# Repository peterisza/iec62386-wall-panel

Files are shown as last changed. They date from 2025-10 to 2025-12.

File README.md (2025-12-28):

This is a smart-home wall panel that is intended to be DALI-compatible when it's finished. It has sensors for temperature, humidity, air pressure, and CO2. Its front is customizable and user-swappable with up to 16 capacitive touch channels.

## Status / Important Notice

This project is a **prototype** and **not a consumer product**. It is under active development and may be incomplete, unstable, or non-compliant with relevant standards.

### DO NOT CONNECT TO A REAL DALI NETWORK (YET)

**Do not connect this device to any production / real DALI installation.**  
The current firmware is not DALI-compliant and is intended for development only. In its current state it will:
- transmit debug frames (e.g., 16-bit debug frames),
- respond incorrectly to forward frames (e.g., fixed/placeholder back frame behavior),
- cause unexpected bus behavior.

## Safety / Disclaimer

- Provided **AS IS**, **WITHOUT WARRANTY** of any kind (express or implied).
- You are solely responsible for verifying **electrical safety**, **EMC**, and **regulatory compliance** before any real-world installation or use.
- Not intended for **safety-critical** or life-safety applications (medical, fire protection, emergency systems, etc.).
- If you 3D-print the enclosure, use appropriate **flame-retardant** materials and follow local building and electrical codes.
- By using, building, or distributing this project (or derivatives), you accept that you do so **at your own risk**.

## DALI Compatibility, Certification, and Trademarks

This project is designed with future DALI compatibility in mind, but it is **NOT DALI certified**.

- Certification is performed by the **DALI Alliance / DiiA**. This project is **not certified** and **not affiliated** with the DALI Alliance / DiiA.
- “DALI” and related marks are trademarks of their respective owners. Any mention is for compatibility and informational purposes only.

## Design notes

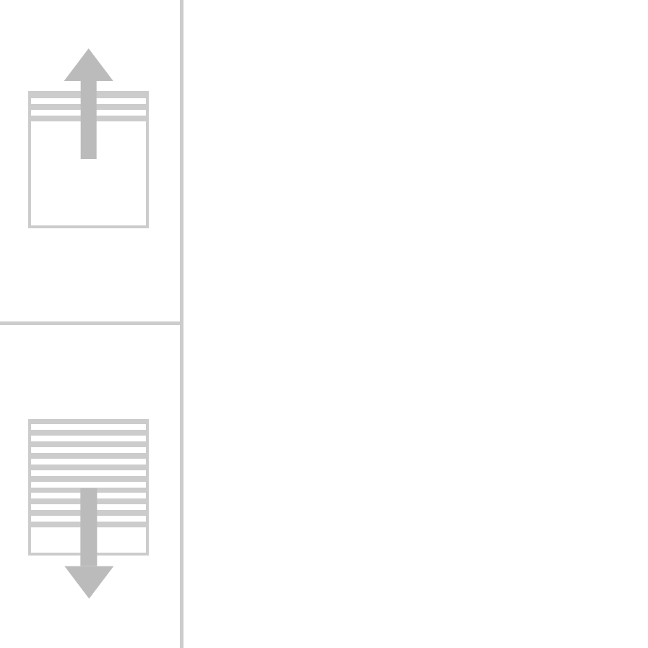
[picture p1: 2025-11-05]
enclosure/button1.png

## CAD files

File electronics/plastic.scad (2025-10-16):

size = 80.5;            
plate_thickness = 2.4;       
air_duct_th = 1.2;
air_duct_w = 8;
screw_enforcement_thickness = 1;
screw_head_height = 2;
pcb_th = 1.6;
box_size = 46;
box_max_r = 57.6/2;
conn_d = 10.5;
behind_pcb = 5;
screw_insulation_h = 3.5;
box_th = 1;
box_corner_r = 6;
clip_width = 10;
clip_h = 2;
screw_distance = 17.5;
screw_hole_d = 3.0;
panel_screw_insulation_d = 5.5;
box_screw_platform_hole_d = 6;
box_screw_hole_d = 3.6;
box_screw_tightness = 0.2;
box_panel_spacing = 0.2;
centered = true;
center = true;
box_start_z = plate_thickness/2;
box_height = conn_d + pcb_th + behind_pcb + box_th;
frame_th = 0;
frame_h = 0;

$fn=100;


module ring(d1, d2, h)
{
    difference() {
        cylinder(d = d1, h = h, center=true);
        cylinder(d = d2, h = h+1, center=true);
    }
}

module screw_head_holes(w, l, h) {
    distance = 30;        // a furatok közepe a középponttól (mm)
    hole_d = 15;
    
    for (ang = [0:90:270]) {
        rotate([0,0,ang])
        translate([distance, 0, 0])
        linear_extrude(h, scale=2.3, center=true)
        projection(cut = true)
        translate([-distance, 0, 0])
        intersection() {
                translate([distance, 0, 0])
                cylinder(d = l, h = h, center=true);

                ring(distance*2+w, distance*2-w, h);
        }
    };
}

module screw_holes(w, l, h) {
    distance = 30;        // a furatok közepe a középponttól (mm)
    hole_d = 15;
    
    intersection() {
        for (ang = [0:90:270]) {
            rotate([0,0,ang])
            translate([distance, 0, 0])
            cylinder(d = l, h = h, center=true);
        };
        ring(distance*2+w, distance*2-w, h);
    }
}



module connector_holes()
{
    distance = 38.6;
    margin = 0.25;
    translate([-distance/2, 0, 0])
       cube([2.65+margin, 25.6+margin, 20], center = true);
    translate([distance/2, 0, 0])
       cube([2.65+margin, 25.6+margin, 20], center = true);
    translate([0, -distance/2, 0])
        cube([14+margin, 2.65+margin, 20], center = true);
    translate([0, distance/2, 0])
        cube([14+margin, 2.65+margin, 20], center = true);
}

module main_plate()
{
    difference() {
        translate([0, 0, +frame_h/2])
        cube([size+2*frame_th, size+2*frame_th, plate_thickness+frame_h], center = centered);
        translate([0, 0, plate_thickness/2+frame_h/2+0.001])
        cube([size, size, frame_h], center = centered);
    }
}

module air_ducts()
{
    w = air_duct_w;
    t = air_duct_th+frame_h;
    pitch = 18;
    displacement = plate_thickness/2-t/2+0.001+frame_h;
    
    translate([-pitch, 0, displacement])
        cube([w, size+5, t], center = true);
    translate([pitch, 0, displacement])
        cube([w, size+5, t], center = true);
    translate([0, pitch, displacement])
        cube([size+5, w, t], center = true);
    translate([0, -pitch, displacement])
        cube([size+5, w, t], center = true);
}

module screw_platform(height, outer, inner)
{
    distance = screw_distance;
    for (ang = [0:90:270]) {
        rotate([0,0,ang])
            translate([-distance,-distance,-height/2])
                ring(outer, inner, height);
    }
}

module pcb_platform(height, outer, inner)
{
    distance = screw_distance;
    for (ang = [0:90:270]) {
        rotate([0,0,ang])
            translate([-distance,-distance,-height/2])
                difference() {
                    cube([outer, outer, height], center = true);
                    cylinder(d = inner, h = height+1, center=true);
                }
    }
}

module rounded_square(r, w, h)
{
    offset(r=r)
        offset(delta=-r)
            square([w, h], center=true);
}

module fucked_up_square(r, w, h)
{
        intersection()
        {
            square([w, h], center=true);
            circle(r = r);
        }
}

module box_guard()
{
    size = 2;
    h = clip_h + 1.5;
    spacing = 0.3;
    guard_h = 2;
    translate([0, 0, -box_start_z-guard_h])
        linear_extrude(guard_h)
        intersection() {
            difference() {
                fucked_up_square(box_max_r + spacing + 2.4, box_size+spacing*2+2.4, box_size+spacing*2+2.4);
                fucked_up_square(box_max_r + spacing, box_size+spacing*2, box_size+spacing*2);
            }
            /*fucked_up_square(box_max_r, box_size, box_size);*/
            circle(box_max_r);
        }
}

module box()
{
    w = box_size;
    h = box_size;
    r = box_corner_r;
    
    conn_w = 16;
    conn_h = 8+box_th;
    conn_x = -5;
    conn_d = behind_pcb + box_th - 0.5;
    
    box_screw_platform_h = behind_pcb - screw_insulation_h - 0.3;
    box_screw_platform_h2 = behind_pcb + box_screw_tightness;
    
    translate([0, 0, -box_height])
    difference() {
        union() {
            linear_extrude(box_height-0.1)
            difference() {
                fucked_up_square(box_max_r, w, h);
                fucked_up_square(box_max_r-box_th, w-box_th*2, h-box_th*2);
            }
            linear_extrude(box_th)
                fucked_up_square(box_max_r, w, h);
            intersection() {
                union()
                {
                    translate([0,0,box_screw_platform_h2+box_th])
                        pcb_platform(box_screw_platform_h2, 8.2, box_screw_platform_hole_d);
                    translate([0,0,box_screw_platform_h+box_th])
                        screw_platform(box_screw_platform_h, 7.7, box_screw_hole_d);
                }
                linear_extrude(box_height-0.1)
                    fucked_up_square(box_max_r-box_th, w-box_th*2, h-box_th*2);
            }

           /* translate([conn_x, +h/2-conn_h/2-box_th/2+0.01, -0.01+conn_d/2])
                cube([conn_w+box_th*2, conn_h+box_th, conn_d], center=true);*/
            
        }
        union() {
            translate([conn_x, +h/2-conn_h/2+0.01, -0.01+conn_d/2])
                cube([conn_w, conn_h, conn_d], center=true);
            translate([0,0,box_th])
                screw_platform(15, box_screw_hole_d, 0);            
            translate([0,0,1])
                screw_platform(1, 6, box_screw_hole_d);
        }
    }
}



/*translate([0, 0, -box_start_z])
box();*/


difference() {
  union() {
   main_plate();
      
   translate([0, 0, -box_start_z])
   intersection()
    {
          union() {
            pcb_platform(conn_d, 8, screw_hole_d);
            screw_platform(conn_d+pcb_th+screw_insulation_h, panel_screw_insulation_d, screw_hole_d);
          }
          translate([0, 0, -50])
          linear_extrude(50)
            fucked_up_square(box_max_r-box_th-box_panel_spacing, box_size-box_th*2-1, box_size-box_th*2-1);
    }
    box_guard();
  }
  union() {
    screw_holes(4, 10, 10);
      translate([0, 0, -screw_head_height/2+plate_thickness/2+0.01])
    screw_head_holes(4, 10, screw_head_height);
    connector_holes();
    air_ducts();
  }
}

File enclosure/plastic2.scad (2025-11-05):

// lekerekített élű lyukak
// chamfered szélű lyukak
// rugalmas támaszték
// support a lyukaknak
// lekerekített tetejű doboz

use <helpers.scad>

$fn = 100;
eps = 0.001;

frame_size = 80;
base_plate_th = 1.2;

base_plate_enforcement_th = 2;
base_plate_enforcement_w = 2;

air_duct_th = 1.2;
air_duct_w = 7;
air_duct_pitch = 19.2;
air_duct_slope = 1.15;

connector_w = 3;
connector_l = 26.6;
connector_dist = 38.6;
connector_r = 1;
connector_h = 9.5;

air_hole_w = 0.1;
air_hole_l = 10;
air_hole_r = 1.5;

standoff_length = 11;
standoff_gap = 0.5;
standoff_th = 0.8;
standoff_w = 5;
standoff_pitch = 31.5;

mounting_hole_dist = 30;
mounting_hole_w = 3.4;
mounting_hole_l = 10;
mounting_hole_base = 0.5;

screw_distance = 17.7;
screw_hole_d = 2.0;
screw_insulation_d = 4.5;
screw_insulation_h = 3.5;
pcb_platform_w = 6;
pcb_th = 1.6;

box_guard_h = 2;
box_guard_th = 2.4;
box_guard_spacing = 0.3;

box_th = 1;
box_size = 46;
box_max_r = 57.6/2;
box_space_behind_pcb = 5;
box_screw_platform_hole_d = 5.2;
box_screw_hole_d = 2.8;
box_screw_tightness = 0.2;
box_panel_spacing = 0.5;
box_screw_head_d = 1.3;

bus_conn_w = 16.5;
bus_conn_h = 8.3;
bus_conn_x = -5.4;

support_th = 0.0;


module air_ducts()
{
    for(a = [0:90:270]) rotate([0,0,a]) {
        mirror([0,0,1]) 
        translate([0, air_duct_pitch, eps])
        linear_extrude(air_duct_th, scale=air_duct_slope)
        square([frame_size+5, air_duct_w], center = true);
    }
}  

module holes_2d()
{
    for(a = [0,180]) rotate([0,0,a]) {
        translate([connector_dist/2, 0, 0])
        offset(connector_r)
        square([connector_w, connector_l], center = true);
        
        translate([0, connector_dist/2, 0])
        offset(air_hole_r)
        square([air_hole_l, air_hole_w], center = true);
    }
}

module holes()
{
    translate([0, 0, -eps])
    linear_extrude(base_plate_th+eps*2)
    holes_2d();
}

module holes_support()
{
    mirror([0,0,1])
    shell(air_duct_th, support_th)
    holes_2d();
}

module standoff_cutout()
{
    for(a = [0:90:270]) rotate([0,0,a]) {
        translate([standoff_pitch, /*-frame_size/2+standoff_length/2+standoff_offset*/standoff_pitch, 0])
        rotate([0,0,45])
        cube([standoff_w, standoff_length, 50], center = true);
    }
}


module standoff()
{
    th = air_duct_th - 0.2;
    for(a = [0:90:270]) rotate([0,0,a]) {
        cutout_length = standoff_length;
        translate([standoff_pitch, standoff_pitch, -standoff_th/2+base_plate_th])
        rotate([0,0,45])
        {
            translate([0, -standoff_gap, 0])
            cube([standoff_w - 2*standoff_gap, standoff_length, standoff_th], center = true);
            
            translate([0, standoff_length/2-standoff_gap*2.5, standoff_th/2 + th/2])
            cube([standoff_w - 2*standoff_gap, 1.5, th], center = true);
        }
    }    
}

module standoff_support()
{
    translate([0,0,+base_plate_th-standoff_th])
    mirror([0,0,1])
    inner_shell(air_duct_th+base_plate_th-standoff_th, support_th)
        projection()
            standoff();
}

module base_plate_enforcement()
{

    for (ang = [45:90:135]) {
        rotate([0, 0, ang])
        translate([0,0,air_duct_th/2+base_plate_enforcement_th/2])
            cube([sqrt(2)*screw_distance*2, base_plate_enforcement_w, base_plate_enforcement_th], center = true);
    }
}

module screw_platform(distance, height, outer, inner)
{
    for (ang = [0:90:270]) {
        rotate([0,0,ang])
        translate([-distance,-distance,-height/2])
        ring(outer, inner, height);
    }
}

module pcb_platform(distance, height, outer, inner)
{
    for (ang = [0:90:270]) {
        rotate([0,0,ang])
        translate([-distance,-distance,-height/2])
        difference() {
            cube([outer, outer, height], center = true);
            cylinder(d = inner, h = height+1, center=true);
        }
    }
}

module frame_pcb_platform()
{
    mirror([0,0,1])
    translate([0, 0, -base_plate_th+eps])
    intersection()
    {
          union() {
            pcb_platform(screw_distance, connector_h, pcb_platform_w, screw_hole_d);
            screw_platform(screw_distance, connector_h+pcb_th+screw_insulation_h, screw_insulation_d, screw_hole_d);
          }
          translate([0, 0, -50])
          linear_extrude(50)
            fucked_up_square(box_max_r-box_th-box_panel_spacing, box_size-box_th*2-1, box_size-box_th*2-1);
    }
}

module box_guard()
{
    spacing = box_guard_spacing;
    translate([0, 0, base_plate_th])
        linear_extrude(box_guard_h)
        intersection() {
            difference() {
                fucked_up_square(box_max_r + spacing + box_guard_th, box_size+spacing*2 + box_guard_th, box_size+spacing*2 + box_guard_th);
                fucked_up_square(box_max_r + spacing, box_size+spacing*2, box_size+spacing*2);
            }
            circle(box_max_r);
        }
}


module screw_head()
{
    cylinder(5, 0.1, 10);
}

module mounting_hole_2d()
{
    offset(r = mounting_hole_w/2)
    intersection() {
        difference() {
            circle(mounting_hole_dist+eps);
            circle(mounting_hole_dist-eps);
        }
        for (ang = [0:90:270])
            rotate([0,0,ang])
            translate([0, mounting_hole_dist, 0])
            circle(mounting_hole_l/2);
    }
}

module mounting_hole()
{
    translate([0,0,base_plate_th - mounting_hole_base])
    mirror([0,0,1]) {
        minkowski() {
            linear_extrude(eps)
                mounting_hole_2d();
            screw_head();
        }
        translate([0, 0, -5])
        linear_extrude(5)
            mounting_hole_2d();
   }
}


module frame()
{
    difference() {
        union() {
            translate([0,0,base_plate_th/2])
            cube([frame_size, frame_size, base_plate_th], center = true);
            
            translate([0,0,-air_duct_th/2])
            cube([frame_size, frame_size, air_duct_th], center = true);
            
            base_plate_enforcement();
            frame_pcb_platform();
            box_guard();
        }
        union() {
            holes();
            air_ducts();
            mounting_hole();
            standoff_cutout();
        }
    }
    standoff();
    holes_support();
    standoff_support();
}

module box()
{
    w = box_size;
    h = box_size;
    
    conn_w = bus_conn_w;
    conn_h = bus_conn_h+box_th;
    conn_x = bus_conn_x;
    conn_d = box_space_behind_pcb + box_th - 0.0;
    
    box_height = connector_h + pcb_th + box_space_behind_pcb + box_th;
    box_screw_platform_h = box_space_behind_pcb - screw_insulation_h - 0.3;
    box_screw_platform_h2 = box_space_behind_pcb + box_screw_tightness;
    
    translate([0, 0, -box_height])
    difference() {
        union() {
            linear_extrude(box_height-0.1)
            difference() {
                fucked_up_square(box_max_r, w, h);
                fucked_up_square(box_max_r-box_th, w-box_th*2, h-box_th*2);
            }
            linear_extrude(box_th)
                fucked_up_square(box_max_r, w, h);
            intersection() {
                union()
                {
                    translate([0,0,box_screw_platform_h2+box_th])
                        pcb_platform(screw_distance, box_screw_platform_h2, 7.7, box_screw_platform_hole_d);
                    translate([0,0,box_screw_platform_h+box_th])
                        screw_platform(screw_distance, box_screw_platform_h, 7.7, box_screw_hole_d);
                }
                linear_extrude(box_height-0.1)
                    fucked_up_square(box_max_r-box_th, w-box_th*2, h-box_th*2);
            }
           /* translate([conn_x, +h/2-conn_h/2-box_th/2+0.01, -0.01+conn_d/2])
                cube([conn_w+box_th*2, conn_h+box_th, conn_d], center=true);*/
        }
        union() {
            translate([conn_x, +h/2-conn_h/2+0.01, -0.01+conn_d/2])
                cube([conn_w, conn_h, conn_d], center=true);
            translate([0,0,box_th+eps])
                screw_platform(screw_distance, 15, box_screw_hole_d, 0);            
            /*translate([0,0,1])
                screw_platform(screw_distance, 1, 6, box_screw_hole_d);*/
            for (ang = [0:90:270]) {
                rotate([0, 0, ang])
                translate([screw_distance, screw_distance, box_screw_head_d])
                mirror([0,0,1])
                screw_head();
            }
        }
    }
    
                /*for (ang = [0:90:270])
                rotate([0, 0, ang])
                translate([screw_distance, screw_distance, -box_height+box_screw_head_d])
                mirror([0,0,1])
                screw_head();*/
}



//translate([0, 0, -50]) box();
frame();

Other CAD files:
enclosure/helpers.scad
enclosure/plastic.scad
enclosure/mold-test.scad

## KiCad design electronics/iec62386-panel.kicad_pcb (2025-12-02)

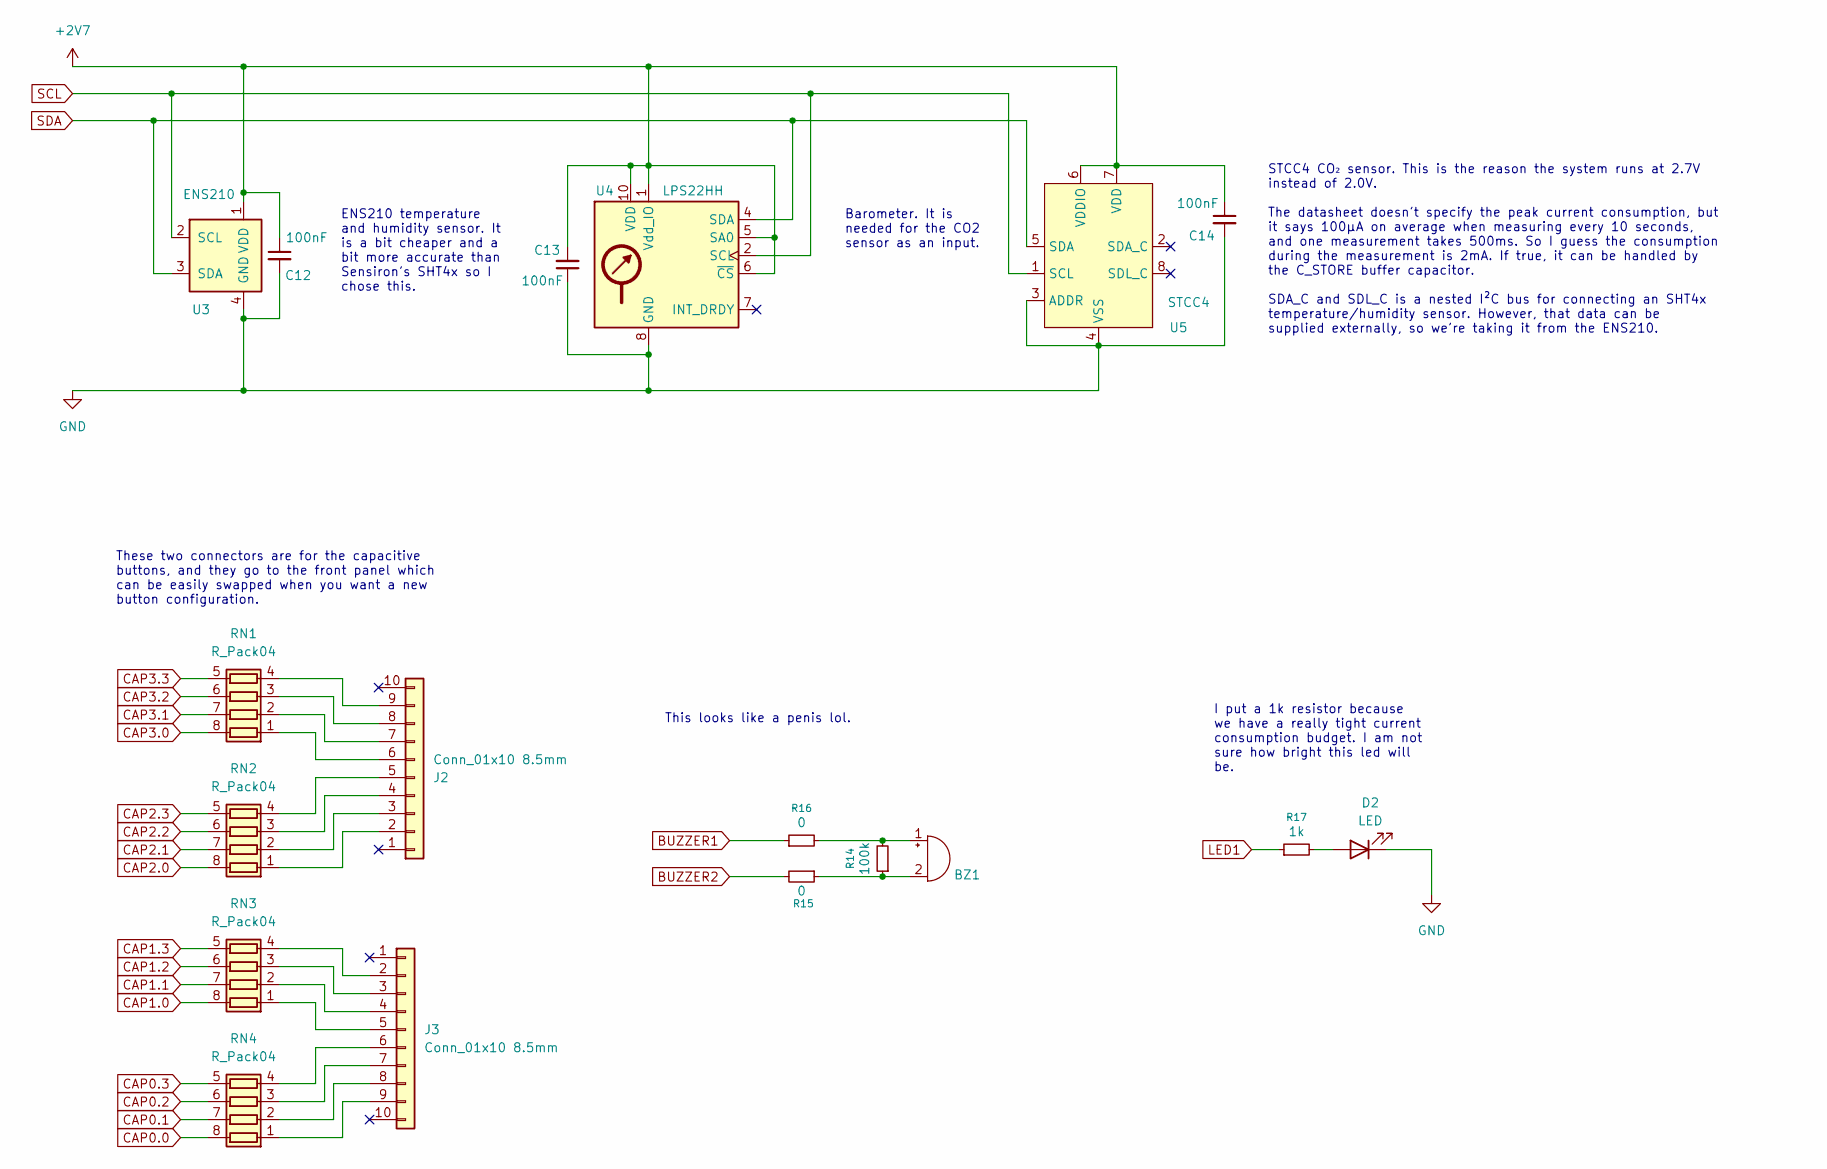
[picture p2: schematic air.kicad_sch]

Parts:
BZ1: Buzzer_CUI_CPT-9019S-SMT
C12, C13, C14: 100nF; C_0603_1608Metric_Pad1.08x0.95mm_HandSolder
D2: LED; LED_0603_1608Metric_Pad1.05x0.95mm_HandSolder
J2, J3: Conn_01x10 8.5mm; PinSocket_1x10_P2.54mm_Vertical
R14: 100k; R_0603_1608Metric_Pad0.98x0.95mm_HandSolder
R15, R16: 0; R_0603_1608Metric_Pad0.98x0.95mm_HandSolder
R17: 1k; R_0603_1608Metric_Pad0.98x0.95mm_HandSolder
RN1, RN2, RN3, RN4: R_Pack04; R_Cat16-4-DEBUG
U3: ENS210; AMS_QFN-4-1EP_2x2mm_P0.95mm_EP0.7x1.6mm-DEBUG
U4: LPS22HH; ST_HLGA-10_2x2mm_P0.5mm_LayoutBorder3x2y-DEBUG
U5: STCC4; STCC4-LGA

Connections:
+2V7: C12.1, C13.2, C14.1, U3.1 (VDD), U4.1 (Vdd_IO), U4.5 (SA0), U4.6 (~CS), U4.10 (VDD), U5.6 (VDDIO), U5.7 (VDD); also elsewhere on the board
BUZZER1: R16.1; also elsewhere on the board
BUZZER2: R15.2; also elsewhere on the board
CAP0.0: RN4.8 (R1.2); also elsewhere on the board
CAP0.1: RN4.7 (R2.2); also elsewhere on the board
CAP0.2: RN4.6 (R3.2); also elsewhere on the board
CAP0.3: RN4.5 (R4.2); also elsewhere on the board
CAP1.0: RN3.8 (R1.2); also elsewhere on the board
CAP1.1: RN3.7 (R2.2); also elsewhere on the board
CAP1.2: RN3.6 (R3.2); also elsewhere on the board
CAP1.3: RN3.5 (R4.2); also elsewhere on the board
CAP2.0: RN2.8 (R1.2); also elsewhere on the board
CAP2.1: RN2.7 (R2.2); also elsewhere on the board
CAP2.2: RN2.6 (R3.2); also elsewhere on the board
CAP2.3: RN2.5 (R4.2); also elsewhere on the board
CAP3.0: RN1.8 (R1.2); also elsewhere on the board
CAP3.1: RN1.7 (R2.2); also elsewhere on the board
CAP3.2: RN1.6 (R3.2); also elsewhere on the board
CAP3.3: RN1.5 (R4.2); also elsewhere on the board
GND: C12.2, C13.1, C14.2, D2.1 (K), U3.4 (GND), U3.5 (GND), U4.3 (GND), U4.8 (GND), U4.9 (GND), U5.3 (ADDR), U5.4 (VSS); also elsewhere on the board
LED1: R17.1; also elsewhere on the board
unnamed: BZ1.1 (+), R14.2, R16.2
unnamed: BZ1.2 (-), R14.1, R15.1
unnamed: D2.2 (A), R17.2
unnamed: J2.2, RN2.1 (R1.1)
unnamed: J2.3, RN2.2 (R2.1)
unnamed: J2.4, RN2.3 (R3.1)
unnamed: J2.5, RN2.4 (R4.1)
unnamed: J2.6, RN1.1 (R1.1)
unnamed: J2.7, RN1.2 (R2.1)
unnamed: J2.8, RN1.3 (R3.1)
unnamed: J2.9, RN1.4 (R4.1)
unnamed: J3.2, RN3.4 (R4.1)
unnamed: J3.3, RN3.3 (R3.1)
unnamed: J3.4, RN3.2 (R2.1)
unnamed: J3.5, RN3.1 (R1.1)
unnamed: J3.6, RN4.4 (R4.1)
unnamed: J3.7, RN4.3 (R3.1)
unnamed: J3.8, RN4.2 (R2.1)
unnamed: J3.9, RN4.1 (R1.1)
SCL: U3.2 (SCL), U4.2 (SCL), U5.1 (SCL); also elsewhere on the board
SDA: U3.3 (SDA), U4.4 (SDA), U5.5 (SDA); also elsewhere on the board

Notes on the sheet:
Barometer. It is needed for the CO2 sensor as an input.
STCC4 CO₂ sensor. This is the reason the system runs at 2.7V instead of 2.0V. The datasheet doesn't specify the peak current consumption, but it says 100µA on average when measuring every 10 seconds, and one measurement takes 500ms. So I guess the consumption during the measurement is 2mA. If true,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
ENS210 temperature and humidity sensor. It is a bit cheaper and a bit more accurate than Sensiron's SHT4x so I chose this.
I put a 1k resistor because we have a really tight current consumption budget. I am not sure how bright this led will be.
These two connectors are for the capacitive buttons, and they go to the front panel which can be easily swapped when you want a new button configuration.
This looks like a penis lol.

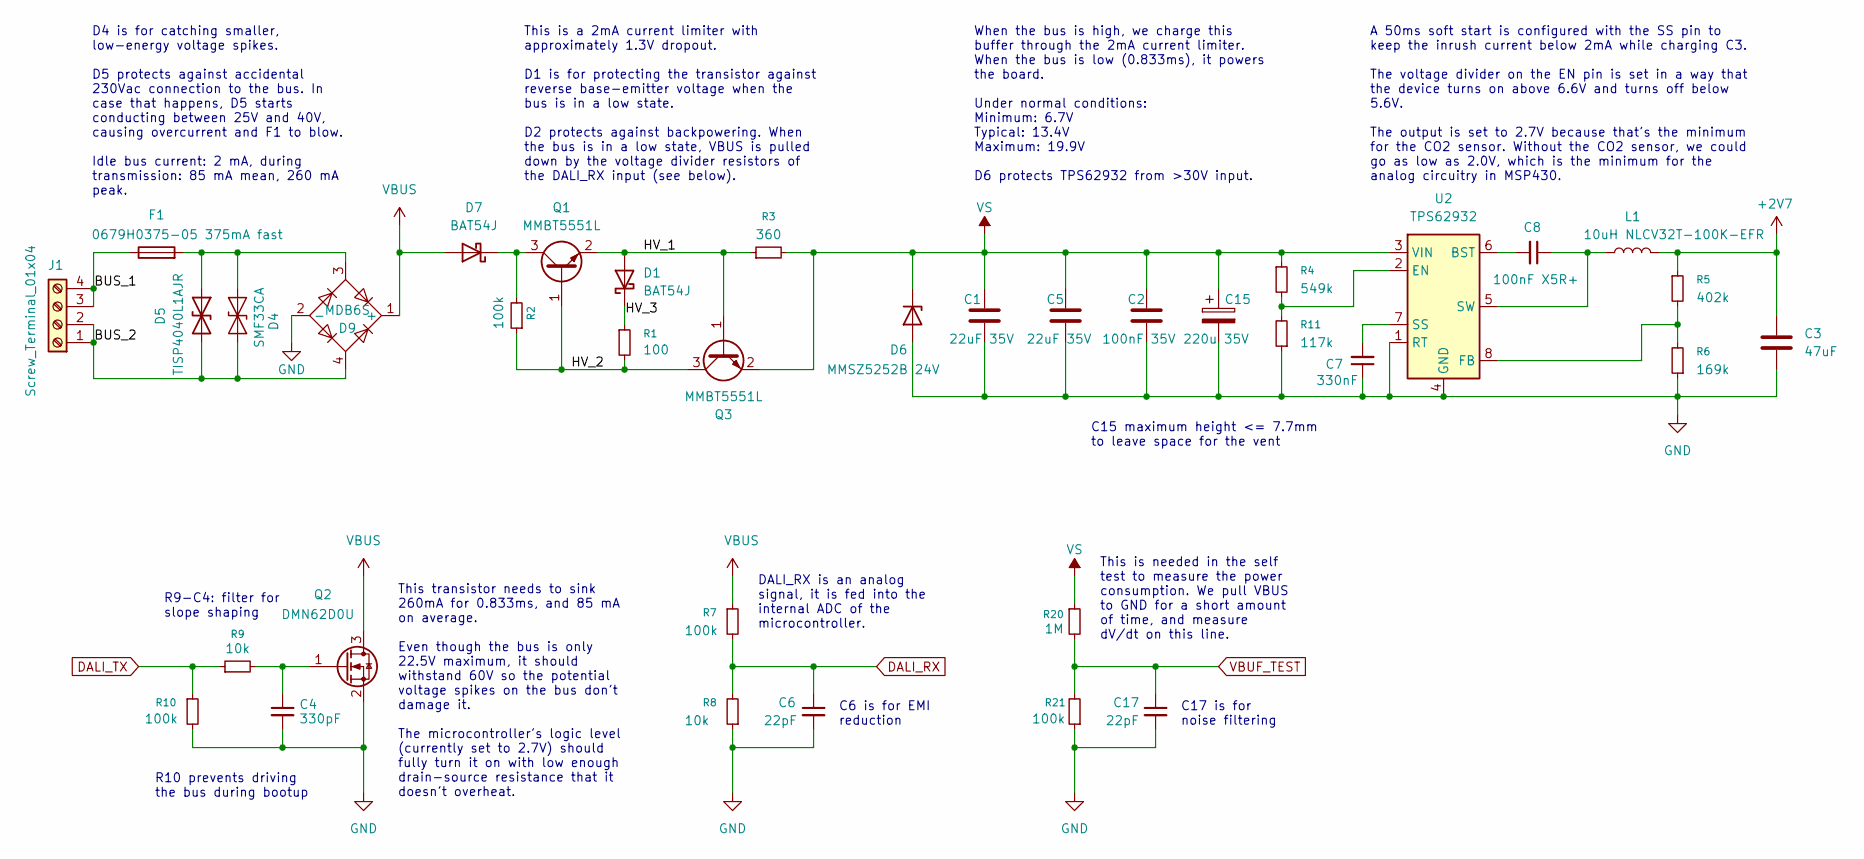
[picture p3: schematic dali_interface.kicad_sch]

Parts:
C1, C5: 22uF 35V; C_1206_3216Metric_Pad1.33x1.80mm_HandSolder
C2: 100nF 35V; C_0603_1608Metric_Pad1.08x0.95mm_HandSolder
C3: 47uF; C_0805_2012Metric_Pad1.18x1.45mm_HandSolder
C4: 330pF; C_0603_1608Metric_Pad1.08x0.95mm_HandSolder
C6, C17: 22pF; C_0603_1608Metric_Pad1.08x0.95mm_HandSolder
C7: 330nF; C_0603_1608Metric_Pad1.08x0.95mm_HandSolder
C8: 100nF X5R+; C_0603_1608Metric_Pad1.08x0.95mm_HandSolder
C15: 220u 35V; CP_Elec_6.3x7.7
D1, D7: BAT54J; D_SOD-323_HandSoldering
D4: SMF33CA; D_SOD-123-DEBUG
D5: TISP4040L1AJR; D_SMA
D6: MMSZ5252B 24V; D_SOD-123F
D9: MDB6S; TSSOP-4_4.4x5mm_P4mm
F1: 0679H0375-05 375mA fast; FUSE_0679H_BEL
J1: Screw_Terminal_01x04; TerminalBlock_MetzConnect_Type086_RT03404HBLC_1x04_P3.81mm_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
L1: 10uH NLCV32T-100K-EFR; L_TDK_NLV32_3.2x2.5mm
Q1, Q3: MMBT5551L; SOT-23
Q2: DMN62D0U; SOT-23
R1: 100; R_0603_1608Metric_Pad0.98x0.95mm_HandSolder
R2, R7, R10, R21: 100k; R_0603_1608Metric_Pad0.98x0.95mm_HandSolder
R3: 360; R_0603_1608Metric_Pad0.98x0.95mm_HandSolder
R4: 549k; R_0603_1608Metric_Pad0.98x0.95mm_HandSolder
R5: 402k; R_0603_1608Metric_Pad0.98x0.95mm_HandSolder
R6: 169k; R_0603_1608Metric_Pad0.98x0.95mm_HandSolder
R8, R9: 10k; R_0603_1608Metric_Pad0.98x0.95mm_HandSolder
R11: 117k; R_0603_1608Metric_Pad0.98x0.95mm_HandSolder
R20: 1M; R_0603_1608Metric_Pad0.98x0.95mm_HandSolder
U2: TPS62932; SOT-583-8-DEBUG

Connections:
+2V7: C3.1, L1.2, R5.1; also elsewhere on the board
/IEC 62386 interface/BUS_1: F1.1, J1.3, J1.4
/IEC 62386 interface/BUS_2: D4.1 (A1), D5.2 (A2), D9.4, J1.1, J1.2
/IEC 62386 interface/HV_1: D1.2 (A), Q1.2 (E), Q3.1 (B), R3.1
/IEC 62386 interface/HV_2: Q1.1 (B), Q3.3 (C), R1.2, R2.1
/IEC 62386 interface/HV_3: D1.1 (K), R1.1
DALI_RX: C6.1, R7.2, R8.2; also elsewhere on the board
DALI_TX: R9.1, R10.1; also elsewhere on the board
GND: C1.2, C2.2, C3.2, C4.2, C5.2, C6.2, C7.1, C15.2, C17.2, D6.2 (A), D9.2 (-), Q2.2 (S), R6.1, R8.1, R10.2, R11.1, R21.1, U2.1 (RT), U2.4 (GND); also elsewhere on the board
unnamed: D4.2 (A2), D5.1 (A1), D9.3, F1.2
unnamed: D7.1 (K), Q1.3 (C), R2.2
unnamed: C4.1, Q2.1 (G), R9.2
unnamed: C8.2, U2.6 (BST)
unnamed: R4.2, R11.2, U2.2 (EN)
unnamed: R5.2, R6.2, U2.8 (FB)
unnamed: C7.2, U2.7 (SS)
unnamed: C8.1, L1.1, U2.5 (SW)
VBUF_TEST: C17.1, R20.2, R21.2; also elsewhere on the board
VBUS: D7.2 (A), D9.1 (+), Q2.3 (D), R7.1
VS: C1.1, C2.1, C5.1, C15.1, D6.1 (K), Q3.2 (E), R3.2, R4.1, R20.1, U2.3 (VIN)

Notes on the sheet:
DALI_RX is an analog signal, it is fed into the internal ADC of the microcontroller.
C17 is for noise filtering
C6 is for EMI reduction
C15 maximum height <= 7.7mm to leave space for the vent
This is a 2mA current limiter with approximately 1.3V dropout. D1 is for protecting the transistor against reverse base-emitter voltage when the bus is in a low state. D2 protects against backpowering. When the bus is in a low state, VBUS is pulled down by the voltage divider resistors of the DALI_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
This is needed in the self test to measure the power consumption. We pull VBUS to GND for a short amount of time, and measure dV/dt on this line.
When the bus is high, we charge this buffer through the 2mA current limiter. When the bus is low (0.833ms), it powers the board. Under normal conditions: Minimum: 6.7V Typical: 13.4V Maximum: 19.9V D6 protects TPS62932 from >30V input.
D4 is for catching smaller, low-energy voltage spikes. D5 protects against accidental 230Vac connection to the bus. In case that happens, D5 starts conducting between 25V and 40V, causing overcurrent and F1 to blow. Idle bus current: 2 mA, during transmission: 85 mA mean, 260 mA peak.
R10 prevents driving the bus during bootup
R9-C4: filter for slope shaping
A 50ms soft start is configured with the SS pin to keep the inrush current below 2mA while charging C3. The voltage divider on the EN pin is set in a way that the device turns on above 6.6V and turns off below 5.6V. The output is set to 2.7V because that's the minimum for the CO2 sensor. Without th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
This transistor needs to sink 260mA for 0.833ms, and 85 mA on average. Even though the bus is only 22.5V maximum, it should withstand 60V so the potential voltage spikes on the bus don't damage it. The microcontroller's logic level (currently set to 2.7V) should fully turn it on with low enough dra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

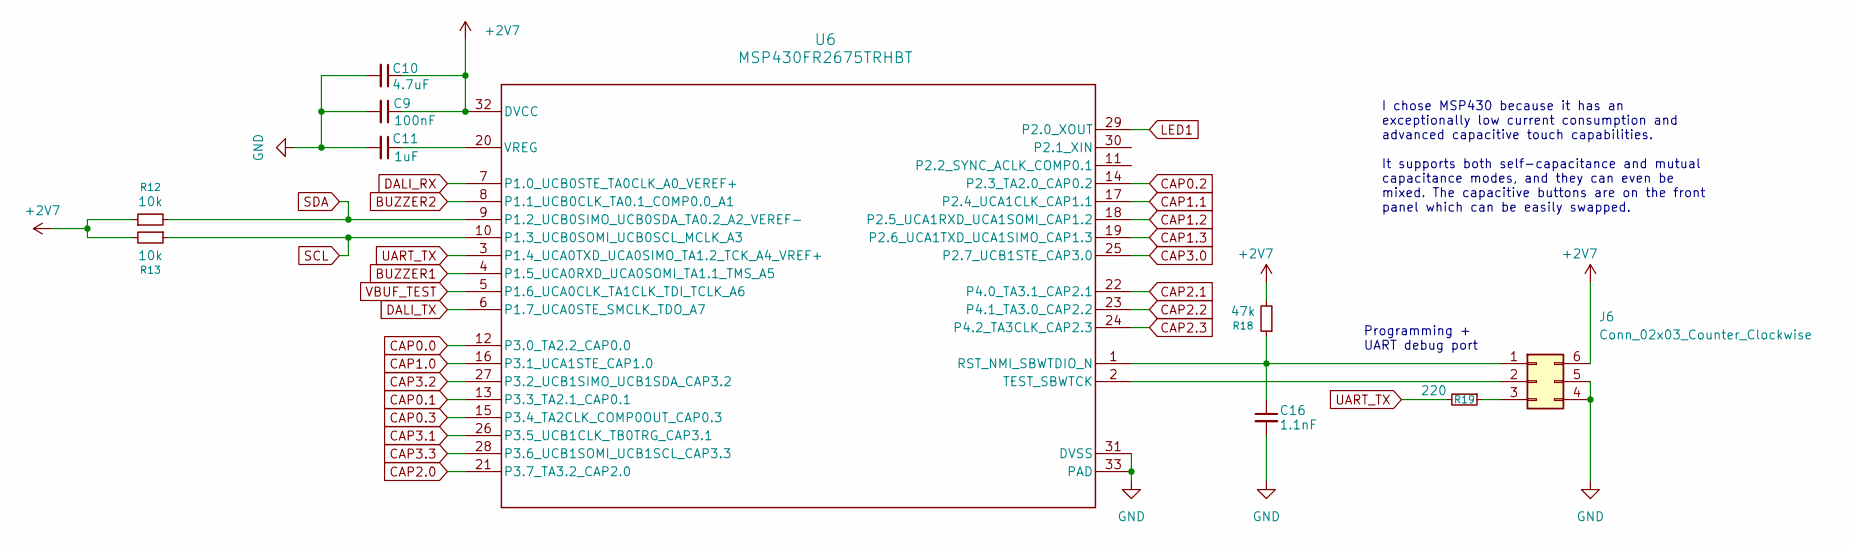
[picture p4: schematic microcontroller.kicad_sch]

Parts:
C9: 100nF; C_0603_1608Metric_Pad1.08x0.95mm_HandSolder
C10: 4.7uF; C_0603_1608Metric_Pad1.08x0.95mm_HandSolder
C11: 1uF; C_0603_1608Metric_Pad1.08x0.95mm_HandSolder
C16: 1.1nF; C_0603_1608Metric_Pad1.08x0.95mm_HandSolder
J6: Conn_02x03_Counter_Clockwise; PinSocket_2x03_P1.27mm_Vertical
R12, R13: 10k; R_0603_1608Metric_Pad0.98x0.95mm_HandSolder
R18: 47k; R_0603_1608Metric_Pad0.98x0.95mm_HandSolder
R19: 220; R_0603_1608Metric_Pad0.98x0.95mm_HandSolder
U6: MSP430FR2675TRHBT; QFN-32-1EP_5x5mm_P0.5mm_EP3.1x3.1mm

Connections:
+2V7: C9.1, C10.1, J6.6, R12.1, R13.2, R18.2, U6.32 (DVCC); also elsewhere on the board
BUZZER1: U6.4 (P1.5_UCA0RXD_UCA0SOMI_TA1.1_TMS_A5); also elsewhere on the board
BUZZER2: U6.8 (P1.1_UCB0CLK_TA0.1_COMP0.0_A1); also elsewhere on the board
CAP0.0: U6.12 (P3.0_TA2.2_CAP0.0); also elsewhere on the board
CAP0.1: U6.13 (P3.3_TA2.1_CAP0.1); also elsewhere on the board
CAP0.2: U6.14 (P2.3_TA2.0_CAP0.2); also elsewhere on the board
CAP0.3: U6.15 (P3.4_TA2CLK_COMP0OUT_CAP0.3); also elsewhere on the board
CAP1.0: U6.16 (P3.1_UCA1STE_CAP1.0); also elsewhere on the board
CAP1.1: U6.17 (P2.4_UCA1CLK_CAP1.1); also elsewhere on the board
CAP1.2: U6.18 (P2.5_UCA1RXD_UCA1SOMI_CAP1.2); also elsewhere on the board
CAP1.3: U6.19 (P2.6_UCA1TXD_UCA1SIMO_CAP1.3); also elsewhere on the board
CAP2.0: U6.21 (P3.7_TA3.2_CAP2.0); also elsewhere on the board
CAP2.1: U6.22 (P4.0_TA3.1_CAP2.1); also elsewhere on the board
CAP2.2: U6.23 (P4.1_TA3.0_CAP2.2); also elsewhere on the board
CAP2.3: U6.24 (P4.2_TA3CLK_CAP2.3); also elsewhere on the board
CAP3.0: U6.25 (P2.7_UCB1STE_CAP3.0); also elsewhere on the board
CAP3.1: U6.26 (P3.5_UCB1CLK_TB0TRG_CAP3.1); also elsewhere on the board
CAP3.2: U6.27 (P3.2_UCB1SIMO_UCB1SDA_CAP3.2); also elsewhere on the board
CAP3.3: U6.28 (P3.6_UCB1SOMI_UCB1SCL_CAP3.3); also elsewhere on the board
DALI_RX: U6.7 (P1.0_UCB0STE_TA0CLK_A0_VEREF+); also elsewhere on the board
DALI_TX: U6.6 (P1.7_UCA0STE_SMCLK_TDO_A7); also elsewhere on the board
GND: C9.2, C10.2, C11.2, C16.2, J6.4, J6.5, U6.31 (DVSS), U6.33 (PAD); also elsewhere on the board
LED1: U6.29 (P2.0_XOUT); also elsewhere on the board
unnamed: C16.1, J6.1, R18.1, U6.1 (RST_NMI_SBWTDIO_N)
unnamed: J6.2, U6.2 (TEST_SBWTCK)
unnamed: J6.3, R19.1
unnamed: C11.1, U6.20 (VREG)
SCL: R13.1, U6.10 (P1.3_UCB0SOMI_UCB0SCL_MCLK_A3); also elsewhere on the board
SDA: R12.2, U6.9 (P1.2_UCB0SIMO_UCB0SDA_TA0.2_A2_VEREF-); also elsewhere on the board
UART_TX: R19.2, U6.3 (P1.4_UCA0TXD_UCA0SIMO_TA1.2_TCK_A4_VREF+)
VBUF_TEST: U6.5 (P1.6_UCA0CLK_TA1CLK_TDI_TCLK_A6); also elsewhere on the board

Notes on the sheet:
I chose MSP430 because it has an exceptionally low current consumption and advanced capacitive touch capabilities. It supports both self-capacitance and mutual capacitance modes, and they can even be mixed. The capacitive buttons are on the front panel which can be easily swapped.
Programming + UART debug port

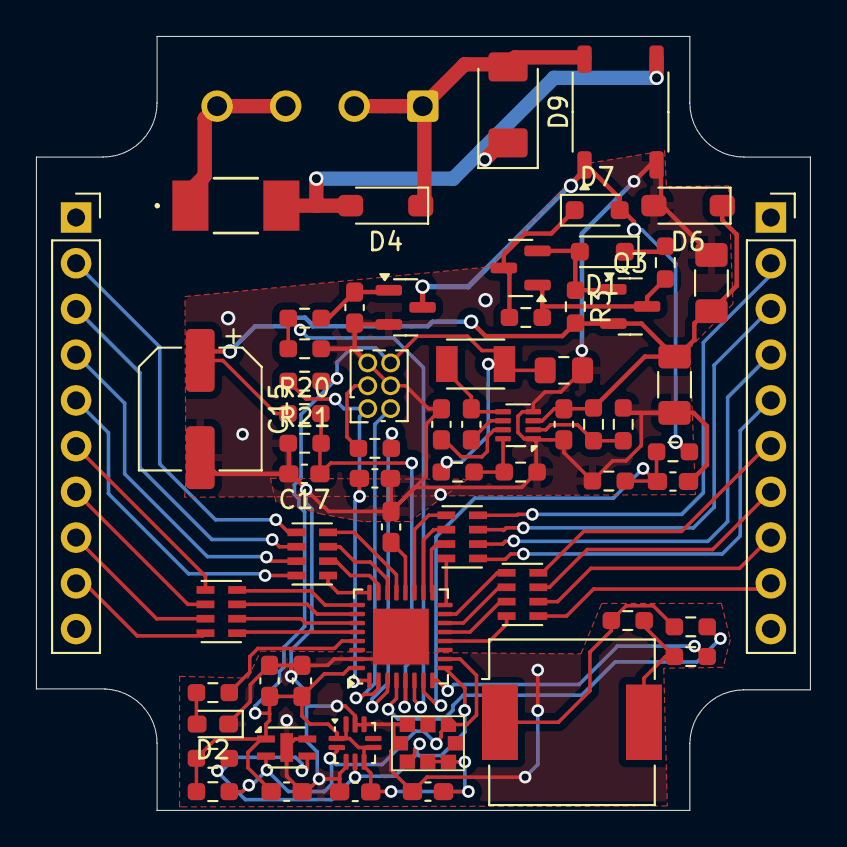
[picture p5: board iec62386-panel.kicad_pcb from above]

Board: 2 copper layers, 43.0 x 43.0 mm, 64 parts (1 on the bottom side), 65 nets.

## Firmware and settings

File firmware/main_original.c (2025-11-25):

#include <msp430.h>
#include <stdbool.h>
#include "uart.h"
#include "watchdog.h"
#include "i2c.h"
#include "util.h"
#include "gpio.h"
#include "ens210_temperature_sensor.h"
#include "lps22hh_barometer.h"
#include "stcc4_co2_sensor.h"
#include "captivate.h"
#include "CAPT_Type.h"
#include "CAPT_UserConfig.h"
#include "CAPT_App.h"
#include "rom_captivate.h"
#include "rom_map_captivate.h"
#include "touch.h"
//#include "buzzer.h"
#include "scheduler.h"
#include "dali_phy_mac.h"
#include "sensors.h"


/* Globális változók (volatile!) */
volatile uint16_t low_event_counter = 0;
volatile uint16_t high_event_counter = 0;

/* HA a header fájlban nincs definiálva az ADCWINC, pótoljuk manuálisan.
Az FR2xx User Guide (SLAU445) szerint az ADCMCTL0 regiszter 5. bitje az. */
#ifndef ADCWINC
#define ADCWINC BIT5
#endif

void init_ADC_WindowComp(void) {
    P1SEL0 |= BIT1;
    P1SEL1 |= BIT1;

    // ADCCTL0: Bekapcsolás, Sample time
    ADCCTL0 = ADCSHT_2 | ADCON; 
    

    // Először nullázzuk ki a felbontás biteket (ADCRES)
    ADCCTL1 &= ~(ADCRES0 | ADCRES1); 
    
    // Majd állítsuk be a Pulse Mode-ot, Szoftver Triggert, SMCLK-t ÉS a 12-bitet (ADCRES_2)
    ADCCTL1 |= ADCSHP | ADCSHS_0 | ADCSSEL_2 | ADCRES_2;
    
    // ADCCTL2: Repeat Single (minden ADCSC-re egyet mér)
    ADCCTL2 = ADCCONSEQ_2; 

    // Memória és Window Comparator (ez marad)
    ADCMCTL0 = ADCINCH_1 | ADCSREF_0 | ADCWINC;
    ADCLO = 910;
    ADCHI = 1213;

    // Interruptok (marad)
    ADCIE = ADCLOIE | ADCHIIE;
    
    // ADC Engedélyezése
    ADCCTL0 |= ADCENC;
}

void init_Timer_Trigger(void) {
    // Timer B0 beállítása 9600 Hz-re
    // 1 MHz / 104 = ~9615 Hz
    TB0CCR0 = 103; 
    
    // Trigger pont (TB0.1 kimenet a belső triggerhez)
    TB0CCR1 = 50;  
    TB0CCTL1 = OUTMOD_3; // Set/Reset mód

    // SMCLK, Up mode, Clear
    TB0CTL = TBSSEL__SMCLK | MC__UP | TBCLR;
}

void test_loop(void) {
    uint16_t prev_low = 0;
    uint16_t prev_high = 0;
    uint8_t timer_1s_counter = 0;
    uint16_t current_adc_val = 0;

    __enable_interrupt();

    while(1) {
        __delay_cycles(100000); // 100ms

        // --- KÉZI TRIGGER ---
        // Ez helyettesíti most a Timert.
        // Megbökjük az ADCSC bitet (Start Conversion)
        ADCCTL0 |= ADCSC; 

        // Várunk picit, hogy biztosan kész legyen (opcionális, de debugnál biztosabb)
        while(ADCCTL1 & ADCBUSY);
        // --------------------

        // Eredmény kiolvasása
        current_adc_val = ADCMEM0;

        uart_send_string("\r\n[DEBUG] ADC: ");
        uart_send_uint_dec(current_adc_val);
        // ... ADC kiírás után ...
        uart_send_string(" [Test: 1000->");
        uart_send_uint_dec(1000); 
        uart_send_string("]");
        // Window események kiírása
        if (low_event_counter != prev_low) {
            uart_send_string(" -> Low IRQ! (Cnt: ");
            uart_send_uint_dec(low_event_counter);
            uart_send_string(")");
            prev_low = low_event_counter;
        }

        if (high_event_counter != prev_high) {
            uart_send_string(" -> High IRQ! (Cnt: ");
            uart_send_uint_dec(high_event_counter);
            uart_send_string(")");
            prev_high = high_event_counter;
        }

        // P1.5 Villogtatás
        timer_1s_counter++;
        if (timer_1s_counter >= 10) {
            timer_1s_counter = 0;
            P1OUT ^= BIT5;
            uart_send_string(" [FLIP P1.5]");
        }
    }
}
/* ADC Interrupt Service Routine */
// A vektor neve ebben a családban ADC_VECTOR (nem ADC12_VECTOR)
#if defined(__TI_COMPILER_VERSION__) || defined(__IAR_SYSTEMS_ICC__)
#pragma vector=ADC_VECTOR
__interrupt void ADC_ISR(void)
#elif defined(__GNUC__)
void __attribute__ ((interrupt(ADC_VECTOR))) ADC_ISR (void)
#else
#error Compiler not supported!
#endif
{
    // Az interrupt vektor regiszter neve is ADCIV
    switch(__even_in_range(ADCIV, ADCIV_ADCIFG)) {
        case ADCIV_NONE: break;
        case ADCIV_ADCOVIFG: break;   // Overflow
        case ADCIV_ADCTOVIFG: break;  // Time overflow
        case ADCIV_ADCHIIFG:          // Window High ( > 0.8V )
            high_event_counter++;
            break;
        case ADCIV_ADCLOIFG:          // Window Low ( < 0.6V )
            low_event_counter++;
            break;
        case ADCIV_ADCINIFG: break;   // Window Inside
        case ADCIV_ADCIFG: break;     // Conversion complete (nincs engedélyezve)
        default: break;
    }
}



int main(void)
{
    disable_watchdog();
    
    // Power-on stabilization delay - critical for reliable startup
    // This ensures clocks and power domains are stable before initialization
    __delay_cycles(100000);        // Wait ~100ms at ~1MHz for clocks to stabilize
    //touch_init();
    
    gpio_init();
    /*buzzer_beep(1000, 100);*/
    uart_init();

    // P1.5 kimenetként (DALI simulation test)
    P1DIR |= BIT5;
    P1OUT |= BIT5;  // kezdetben HIGH
    
    // ADC window comparator inicializálása
    init_ADC_WindowComp();
    init_Timer_Trigger();   
    test_loop();

    //buzzer_init(0);
    i2c_init(1000000u, 100000u);
    
    sensors_init();
    /*dali_phy_init(dali_frame_callback);
    dali_phy_enable();*/

 
    __bis_SR_register(GIE);        // globál interrupt engedély
    scheduler_init(g_uiApp.ui16ActiveModeScanPeriod, 1000);

    scheduler_add_task(ens210_start_measurement_task, 250);
    scheduler_add_task(ens210_read_results_task, 4000);

    scheduler_add_task(lps22hh_start_measurement_task, 500);
    scheduler_add_task(lps22hh_read_results_task, 4000);

    scheduler_add_task(stcc4_push_compensation_task, 300);
    scheduler_add_task(stcc4_start_measurement_task, 400);
    scheduler_add_task(stcc4_read_results_task, 5000);

    for(;;)
    {
        CAPT_appHandler();        // ez indítja a scanneket és hívja a callbacket
        
        
        if(g_eventTap) {
            //buzzer_beep(2000, 5);
            uart_send_string("Tap\r\n");
            g_eventTap = 0;
        }
        if(g_eventUp) {
            //buzzer_beep(4000, 5);
            uart_send_string("Up\r\n");
            g_eventUp = 0;
        }
        if(g_eventDown) {
            //buzzer_beep(1000, 5);
            uart_send_string("Down\r\n");
            g_eventDown = 0;
        }


        scheduler_tick();        
        CAPT_appSleep();
    }
    
}

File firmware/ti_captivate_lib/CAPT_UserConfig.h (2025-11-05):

/* --COPYRIGHT--,BSD
 * Copyright (c) 2017, Texas Instruments Incorporated
 * All rights reserved.
 *
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
 * *  Redistributions of source code must retain the above copyright
 *    notice, this list of conditions and the following disclaimer.
 *
 * *  Redistributions in binary form must reproduce the above copyright
 *    notice, this list of conditions and the following disclaimer in the
 *    documentation and/or other materials provided with the distribution.
 *
 * *  Neither the name of Texas Instruments Incorporated nor the names of
 *    its contributors may be used to endorse or promote products derived
 *    from this software without specific prior written permission.
 *
 * THIS SOFTWARE IS PROVIDED BY THE COPYRIGHT HOLDERS AND CONTRIBUTORS "AS IS"
 * AND ANY EXPRESS OR IMPLIED WARRANTIES, INCLUDING, BUT NOT LIMITED TO,
 * THE IMPLIED WARRANTIES OF MERCHANTABILITY AND FITNESS FOR A PARTICULAR
 * PURPOSE ARE DISCLAIMED. IN NO EVENT SHALL THE COPYRIGHT OWNER OR
 * CONTRIBUTORS BE LIABLE FOR ANY DIRECT, INDIRECT, INCIDENTAL, SPECIAL,
 * EXEMPLARY, OR CONSEQUENTIAL DAMAGES (INCLUDING, BUT NOT LIMITED TO,
 * PROCUREMENT OF SUBSTITUTE GOODS OR SERVICES; LOSS OF USE, DATA, OR PROFITS;
 * OR BUSINESS INTERRUPTION) HOWEVER CAUSED AND ON ANY THEORY OF LIABILITY,
 * WHETHER IN CONTRACT, STRICT LIABILITY, OR TORT (INCLUDING NEGLIGENCE OR
 * OTHERWISE) ARISING IN ANY WAY OUT OF THE USE OF THIS SOFTWARE,
 * EVEN IF ADVISED OF THE POSSIBILITY OF SUCH DAMAGE.
 * --/COPYRIGHT--*/


// Generated by Captivate Design Center v1_83_00_08 on Tue Oct 28 18:23:40 CET 2025


//*****************************************************************************
// CAPT_UserConfig.h
//
//! The Captivate touch library UserConfig component defines the architecture
//! of the capacitive touch panel that is being implemented.
//
//! \version 1.83.00.05
//! Released on May 15, 2020
//
//*****************************************************************************

//*****************************************************************************
//
// NOTE: This is an automatically generated source code file!  The Captivate
// Design Center generates the User Configuration file automatically based
// upon the sensor layout that was created.
//
// Changes to this file will be OVERWRITTEN if a you select
// "Update Existing Project" under "Generate Source Code" in the Design Center.
//
// To avoid interference with the code generation process, keep ALL application
// code external to this file.
//
//*****************************************************************************

#ifndef CAPT_USERCONFIG_H_
#define CAPT_USERCONFIG_H_

//
// CapTIvate User Configuration Template Version
//
#ifndef __CAPTIVATE_CONFIG_VERSION__
#define __CAPTIVATE_CONFIG_VERSION__ 18300
#endif

//
// Include the CapTIvate Software Library
//
#include "captivate.h"

//
// Compile-Time System Configuration Definitions
//
#define CAPT_SENSOR_COUNT                     (1)
#define CAPT_INTERFACE  (__CAPT_NO_INTERFACE__)
#define CAPT_WAKEONPROX_ENABLE  (false)
#define CAPT_WAKEONPROX_SENSOR  (none)
#define CAPT_TRACKPAD_ENABLE  (false)
#define CAPT_LOW_POWER_MODE (LPM0_bits)
#define CAPT_DVCC_CHARGE_ENABLED  (false)

//
// Compile-Time Noise Immunity Configuration Definitions
//
#define CAPT_CONDUCTED_NOISE_IMMUNITY_ENABLE  (false)
#define CAPT_INPUT_IMPEDANCE_BIAS_CURRENT  (eZeroIbias)
#define CAPT_SELF_MODE_CONVERSION_STYLE  (eMultiFrequencyWithOutlierRemoval)
#define CAPT_PROJ_MODE_CONVERSION_STYLE  (eMultiFrequencyWithOutlierRemoval)
#define CAPT_SELF_MODE_OVERSAMPLING_STYLE  (eNoOversampling)
#define CAPT_PROJ_MODE_OVERSAMPLING_STYLE  (eNoOversampling)
#define CAPT_NOISE_THRESHOLD  (50)
#define CAPT_CALIBRATION_NOISE_LIMIT  (50)
#define CAPT_DYNAMIC_THRESHOLD_ADJUSTMENT  (false)

//
// Compile-Time Device-Specific Features
//
#define CAPT_HAS_ELECTRODE_CHARGE_VOLTAGE_SOURCE_SELECT (true)
#define CAPT_HAS_AUTO_NOISE_IMMUNITY                    (true)
#define CAPT_HAS_ADJUSTABLE_SAMPLING_CAPACITOR_SIZE     (true)
#define CAPT_HAS_INPUT_IMPEDANCE_BIAS_CURRENT           (true)
#define CAPT_HAS_ADDITIONAL_CURRENT_MIRROR              (true)

//
// Captivate Frequency Count Definitions
// If conducted noise is enabled, multiple
// frequency scanning is enabled.  These definitions
// ensure that RAM space is set aside to store
// frequency specific information.
//
#if CAPT_CONDUCTED_NOISE_IMMUNITY_ENABLE
#define CAPT_SELF_FREQ_CNT        (4)
#define CAPT_MUTUAL_FREQ_CNT      (4)
#else
#define CAPT_SELF_FREQ_CNT        (1)
#define CAPT_MUTUAL_FREQ_CNT      (1)
#endif

//*****************************************************************************
//
//! \def CAPT_MS_TO_CYCLES is a macro to convert a period value in 
//! milliseconds to an approximate cycle count based on a 
//! 32.768 kHz clock frequency.
//
//*****************************************************************************
#define CAPT_MS_TO_CYCLES(ms)                                         (ms * 32)
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

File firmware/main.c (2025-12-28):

#include <msp430.h>
#include "uart.h"
#include "watchdog.h"
#include "i2c.h"
#include "util.h"
#include "led.h"
#include "buzzer.h"
#include "touch.h"
#include "clock.h"
#include "scheduler.h"
#include "sensors.h"
#include "captivate.h"
#include "dali_phy_mac.h"
#include "dali_device_generic.h"
#include "random.h"

#define CLOCK_HZ 8000000u

void send_ens210_data_task(void)
{
    if(g_ens210_data.valid) {
        int16_t temp = g_ens210_data.temperature_C * 10 + 500;
        dali_tx_send_frame(0x9000 | (temp & 0xFFF), 16);
        int16_t humidity = g_ens210_data.humidity_RH * 10;
        dali_tx_send_frame(0xA000 | (humidity & 0xFFF), 16);
    }
}

void send_lps22hh_data_task(void)
{
    if(g_lps22hh_data.valid) {
        int16_t pressure = g_lps22hh_data.pressure_hPa;
        dali_tx_send_frame(0xB000 | (pressure & 0xFFF), 16);
    }
}


void send_stcc4_data_task(void)
{
    if(g_stcc4_data.valid) {
        int16_t co2 = g_stcc4_data.co2_ppm / 10;
        dali_tx_send_frame(0xC000 | (co2 & 0xFFF), 16);
    }
}

int main(void)
{
    disable_watchdog();
    PM5CTL0 &= ~LOCKLPM5;
    
    clock_init_8mhz();
    delay_ms_8mhz(200); 
    led_init();

    uart_init();
    buzzer_init(CLOCK_HZ);
    buzzer_beep(1000, 100);
    
    // Generate random seed from ADC noise and initialize RNG
    uint16_t random_seed = generate_random_seed_from_adc();
    random_init(random_seed);
    
    // Print seed to UART for verification
    uart_send_string("Random seed: ");
    uart_send_hex((uint8_t*)&random_seed, 2);
    uart_send_string("\r\n");
    
    dali_phy_init();
    dali_phy_set_frame_callback(process_dali_frame);
    
    i2c_init(CLOCK_HZ, 100000u);

    sensors_init();
    delay_ms_8mhz(100);

    touch_init();
    
    // Configure P1.5 as GPIO Output
    // Stop Timer A1 first (already done in adc_init, but ensure it's stopped)
    TA1CTL = MC__STOP | TACLR;
    TA1CCTL1 = 0;

    __bis_SR_register(GIE);        // Enable global interrupts

    uint16_t loop_counter = 0;

    scheduler_init(g_uiApp.ui16ActiveModeScanPeriod, 1000);

    scheduler_add_task(ens210_start_measurement_task, 250);
    scheduler_add_task(ens210_read_results_task, 100);
    scheduler_add_task(send_ens210_data_task, 4000);

    scheduler_add_task(lps22hh_start_measurement_task, 500);
    scheduler_add_task(lps22hh_read_results_task, 100);
    scheduler_add_task(send_lps22hh_data_task, 4000);

    scheduler_add_task(stcc4_push_compensation_task, 300);
    scheduler_add_task(stcc4_start_measurement_task, 400);
    scheduler_add_task(stcc4_read_results_task, 100);
    scheduler_add_task(send_stcc4_data_task, 5000);

    uart_send_string("==== DALI PHY test ====\r\n");
    uint16_t cycles1 = 1000;
    uint16_t cycles2 = 1000;
    uint8_t periods = 1;
    
    while(1) {
        CAPT_appHandler();
        if(g_eventTap) {
            buzzer_click(750, 50, 10);
            uart_send_string("Tap\r\n");
            dali_tx_send_frame(0x8001, 16);
            g_eventTap = 0;
        }
        if(g_eventTouch) {
            buzzer_click(750, 100, 10);
            uart_send_string("Touch\r\n");
            g_eventTouch = 0;
        }
        if(g_eventHold) {
            //buzzer_beep(3000, 5);
            uart_send_string("Hold\r\n");
            dali_tx_send_frame(0x8002, 16);
            g_eventHold = 0;
        }
        if(g_eventSwipeUp) {
            //buzzer_click(250);
            //buzzer_beep(2000, 50);
            buzzer_click(50, 50, 50);
            uart_send_string("Swipe Up\r\n");
            dali_tx_send_frame(0x8003, 16);
            g_eventSwipeUp = 0;
        }
        if(g_eventSwipeDown) {
            //buzzer_click(250);
            //buzzer_beep(1000, 50);
            buzzer_click(3000, 50, 50);
            uart_send_string("Swipe Down\r\n");
            dali_tx_send_frame(0x8004, 16);
            g_eventSwipeDown = 0;
        }
        if(g_eventUp) {
            //buzzer_click(50);
            buzzer_click(750, 50, 10);
            uart_send_string("Up\r\n");
            dali_tx_send_frame(0x8005, 16);
            g_eventUp = 0;
        }
        if(g_eventDown) {
            //buzzer_click(50);
            buzzer_click(750, 50, 10);
            uart_send_string("Down\r\n");
            dali_tx_send_frame(0x8006, 16);
            g_eventDown = 0;
        }
        if(g_debug_frame != 0) {
            uart_send_string("Debug frame: ");
            uart_send_hex((uint8_t*)&g_debug_frame, 2);
            uart_send_string("\r\n");
            if((g_debug_frame & 0xF000) == 0x8000) {
                cycles1 = (g_debug_frame & 0x0FFF) << 2;
            } else if((g_debug_frame & 0xF000) == 0x9000) {
                cycles2 = (g_debug_frame & 0x0FFF) << 2;
            } else if((g_debug_frame & 0xF000) == 0xA000) {
                periods = g_debug_frame & 0xFF;
            }
            uart_send_string("Cycles1: ");
            uart_send_uint_dec(cycles1);
            uart_send_string(" ");
            uart_send_string("Cycles2: ");
            uart_send_uint_dec(cycles2);
            uart_send_string(" ");
            uart_send_string("Periods: ");
            uart_send_uint_dec(periods);
            uart_send_string("\r\n");
            g_debug_frame = 0;
        }
        /*loop_counter += g_uiApp.ui16ActiveModeScanPeriod;
        if(loop_counter >= 1000) {
            loop_counter = 0;
            buzzer_click(cycles1, cycles2, periods);
        }*/
        scheduler_tick();
        CAPT_appSleep();
    }
}

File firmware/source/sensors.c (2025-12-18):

#include "sensors.h"
#include "uart.h"
#include "util.h"

void ens210_start_measurement_task(void)
{
    ens210_start_single_shot(ENS210_START_T | ENS210_START_H);
}

void lps22hh_start_measurement_task(void)
{
    lps22hh_start_one_shot(LPS22HH_ADDR_SA0_VDD);
}

void stcc4_start_measurement_task(void)
{
    stcc4_start_single_shot(STCC4_ADDR_GND);
}

void stcc4_push_compensation_task(void)
{
    stcc4_push_compensation(STCC4_ADDR_GND, g_ens210_data.temperature_C, g_ens210_data.humidity_RH, g_lps22hh_data.pressure_hPa * 100);
}

void ens210_read_results_task(void)
{
    g_ens210_data.valid = false;
    if (!ens210_read_results(&g_ens210_data)) {
        uart_send_status_prefix(false);
        uart_send_string("ENS210 read failed\r\n");
        return;
    }

    uart_send_status_prefix(g_ens210_data.t_valid_crc_ok);
    uart_send_string("ENS210 Temperature: ");
    uart_send_string(ftoa(g_ens210_data.temperature_C));
    uart_send_string(" C ");
    uart_send_string(g_ens210_data.t_valid_crc_ok ? "(CRC ok)\r\n" : "(CRC error)\r\n");

    uart_send_status_prefix(g_ens210_data.h_valid_crc_ok);
    uart_send_string("ENS210 Humidity: ");
    uart_send_string(ftoa(g_ens210_data.humidity_RH));
    uart_send_string("% ");
    uart_send_string(g_ens210_data.h_valid_crc_ok ? "(CRC ok)\r\n" : "(CRC error)\r\n");
    
    g_ens210_data.valid = g_ens210_data.t_valid_crc_ok && g_ens210_data.h_valid_crc_ok;
    //buzzer_beep(3000, 10);
}

void lps22hh_read_results_task(void)
{
    g_lps22hh_data.valid = false;
    if (!lps22hh_read_results(LPS22HH_ADDR_SA0_VDD, &g_lps22hh_data)) {
        uart_send_status_prefix(false);
        uart_send_string("LPS22HH read failed\r\n");
        return;
    }

    bool pressure_ok = (g_lps22hh_data.pressure_hPa >= 900.0f) && (g_lps22hh_data.pressure_hPa <= 1100.0f);

    uart_send_status_prefix(pressure_ok);
    uart_send_string("LPS22HH Pressure: ");
    uart_send_string(ftoa(g_lps22hh_data.pressure_hPa));
    uart_send_string(" hPa");
    if (!pressure_ok) {
        uart_send_string(" (out of 900-1100 range)");
    }
    uart_send_string("\r\n");

    bool temp_ok = false;
    if (g_ens210_data.t_valid_crc_ok) {
        float diff = g_lps22hh_data.temperature_C - g_ens210_data.temperature_C;
        if (diff < 0.0f) diff = -diff;
        temp_ok = (diff <= 2.0f);
    }

    uart_send_status_prefix(temp_ok);
    uart_send_string("LPS22HH Temperature: ");
    uart_send_string(ftoa(g_lps22hh_data.temperature_C));
    uart_send_string(" C");
    if (!temp_ok && g_ens210_data.t_valid_crc_ok) {
        uart_send_string(" (delta > 2C)");
    }
    uart_send_string("\r\n");
    g_lps22hh_data.valid = g_ens210_data.t_valid_crc_ok && temp_ok;
    //buzzer_beep(3500, 10);
}

void stcc4_read_results_task(void)
{
    g_stcc4_data.valid = false;
    if (!stcc4_read_measurement(STCC4_ADDR_GND, &g_stcc4_data)) {
        uart_send_status_prefix(false);
        uart_send_string("STCC4 read failed\r\n");
        return;
    }

    uart_send_status_prefix(g_stcc4_data.crc_ok);
    uart_send_string("STCC4 CO2: ");
    uart_send_string(ftoa(g_stcc4_data.co2_ppm));
    uart_send_string(" ppm\r\n");

    uart_send_status_prefix(g_stcc4_data.crc_ok);
    uart_send_string("STCC4 Temperature: ");
    uart_send_string(ftoa(g_stcc4_data.temperature_C));
    uart_send_string(" C\r\n");

    uart_send_status_prefix(g_stcc4_data.crc_ok);
    uart_send_string("STCC4 Humidity: ");
    uart_send_string(ftoa(g_stcc4_data.humidity_RH));
    uart_send_string("% ");
    uart_send_string(g_stcc4_data.crc_ok ? "(CRC ok)\r\n" : "(CRC error)\r\n");
    g_stcc4_data.valid = g_stcc4_data.crc_ok;
    //buzzer_beep(4000, 10);
}

void sensors_init(void)
{
    lps22hh_init(LPS22HH_ADDR_SA0_VDD);
}

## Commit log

2025-10-16 Initial commit of the HW
    [air.kicad_sch, dali_interface.kicad_sch, iec62386-panel.kicad_pcb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]
2025-10-21 Plastic frame and enclosure
    [plastic.scad]
2025-10-21 Added mouse ears, fixed connector hole sizes, decreased box height
    [plastic.scad]
2025-10-24 Got the touch panel to do something, modified the enclosure a little bit
    [CAPT_App.obj, CAPT_BSP.obj, CAPT_ISR.obj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]
2025-11-05 Added wall standoff to frame, refactored openscad code, added clay mold test model
    [helpers.scad, mold-test.scad, plastic2.scad]
2025-11-05 Refactored the firmware Now the sensors and the touch sensor work simultaneously
    [CAPT_App.obj, CAPT_BSP.obj, CAPT_ISR.obj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]
2025-11-25 todo + debugging weird analog glitches, trying to make the firmware work
    dali initial test code
    [buzzer.c, dali_phy_mac.c, ens210_temperature_sensor.c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]
2025-11-27 finally able to receive and decode dali forward frames and respond to them with a backward frame
2025-12-02 Fixed errors of the first hw prototype
    [air.kicad_sch, dali_interface.kicad_sch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]
2025-12-02 front panel test pcb
    [iec62386-panel-front-test-B_Cu.gbr, iec62386-panel-front-test-B_Mask.gbr, iec62386-panel-front-test-B_Paste.gbr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]
2025-12-07 now everything works: reading sensor data, capacitive touch, receiving and sending DALI frames
    most of DALI isn't implemented still
2025-12-07 a bit of refactoring + fixed the clock frequency for captivate
    [dali_phy_mac.c, main.c]
2025-12-09 added DALI collision handling, removed collision handling from backward frames
    [dali_phy_mac.c, main.c, random.c]
2025-12-10 Now using ADC interrupt instead of timer interrupt for DALI, fixed obvious error in collision handling
    [dali_device_generic.c, dali_phy_mac.c, main.c]
